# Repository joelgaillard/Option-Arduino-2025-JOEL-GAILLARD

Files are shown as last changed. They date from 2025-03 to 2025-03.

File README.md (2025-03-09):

# Matrix quiz - Documentation du Projet

Réalisé par `Joël Gaillard`
Option Arduino 2025 – COMEM+

[Code source](./main/main.ino) (./main/main.ino)
[Fichier Fritzing du schema](./docs/schematics.fzz) (./docs/schematics.fzz)
[Vidéo de démonstration du projet](./docs/assets/matrix-quiz-video-demo.mp4) (./docs/assets/matrix-quiz-video-demo.mp4)

## 1. Description et motivations du projet

### 1.1 Description

Ce projet consiste en un jeu interactif utilisant une matrice LED 8x8, trois écrans LCD 16x2, des leds et des boutons-poussoirs pour créer une expérience ludique et éducative. Le joueur doit identifier des images simples affichées sur la matrice LED et choisir la bonne réponse parmi trois propositions affichées sur trois écrans LCD distincts.

Le jeu comporte **trois modes** :

1. **Mode "Normal"** : 3 vies, score basé sur le temps et les erreurs.
2. **Mode "Time Limit"** : 4 secondes max par question.
3. **Mode "Mort subite"** : Une seule erreur met fin à la partie.

### 1.2 Motivations

- Expérimentation de divers composants arduino (dont la matrice que je trouve particulièrement intéressante)
- Proposer un mini-jeu ludique et interactif avec différents modes de jeux
- Proposer un passe temps lors de courts moments d'ennui à la HEIG-VD (lorsque l'on attend à la pause que la machine ait fini de faire le café par exemple :) )

## 2. État de l'art

### Projets similaires et inspirants

- Projet de quiz utilisant des leds, un lcd 16x2 et un buzzer: https://www.youtube.com/watch?v=HU-3VD1_Pgg
- Projet de dessins simples sur une matrice led arduino: https://youtube.com/shorts/jsiKtfHeaLs?si=bqF50zugfB3S6R69

## 3. Prototype final

Matrix Quiz

Matrix Quiz

Matrix Quiz

## 4. Circuit électronique

### Schéma

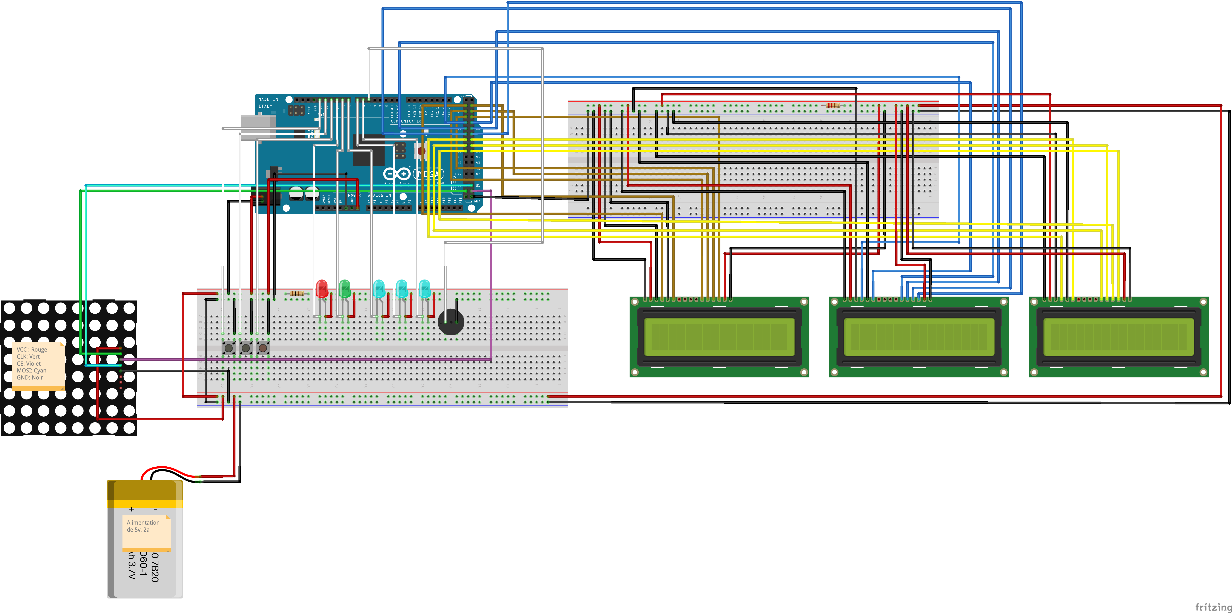
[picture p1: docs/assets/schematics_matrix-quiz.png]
Schéma du circuit


### BOM

| Réf  | Composant | Quantité | Description | Fournisseur / Lien |
| :--- | :--- | --- | :--- | :--- |
| 1 | Arduino Mega 2560 | 1 | Microcontrôleur ATmega2560, 54 I/O, 16 ADC | [Arduino](https://store.arduino.cc/products/arduino-mega-2560-rev3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) |
| 2 | Breadboard | 1 | Plaque de prototypage sans soudure | [Galaxus](https://www.galaxus.ch/de/s1/product/oem-steckplatine-breadboard-transparent-fullsize-breadboard-elektronikzubehoer-gehaeuse-5999390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) |
| 3 | Cable USB A-B | 1 | Alimentation et programmation Arduino | [Galaxus](https://www.galaxus.ch/fr/s1/product/value-usb-a-usb-b-3-m-usb-20-cable-usb-219216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) |
| 4 | 52Pi 8x8 RGB-Matrix mit 4 x 74HC595 - für Raspberry Pi und Arduino | 1 | Affichage matriciel couleur, 64 LEDs | [Play-Zone](https://www.play-zone.ch/en/52pi-8x8-rgb-matrix-mit-4-x-74hc595-fur-raspberry-pi-und-arduino.html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) |
| 5 | Joy-it com-lcd 16x2 Module écran 6.6 cm (2.6 pouces) 16 x 4 Pixel | 3 | Affichage alphanumérique 16 caractères x 2 lignes | [Conrad](https://www.conrad.ch/fr/p/joy-it-com-lcd-16x2-module-ecran-6-6-cm-2-6-pouces-16-x-4-pixel-convient-pour-kits-de-developpement-arduino-avec-re-1656369.html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) |
| 6 | Boutons poussoirs Sparkfun COM-10302 | 3 | Interrupteurs momentanés pour interaction | [Mouser](https://www.mouser.ch/ProductDetail/SparkFun/COM-10302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) |
| 7 | Leds bleues | 3 | Indicateur visuel | [Arduino](https://store.arduino.cc/products/set-of-70-assorted-color-5mm-leds?queryID=1b061a37cc74efad95f1c7123696f21e) |
| 8 | Led rouge | 1 | Indicateur d'erreur | [Arduino](https://store.arduino.cc/products/set-of-70-assorted-color-5mm-leds?queryID=1b061a37cc74efad95f1c7123696f21e) |
| 9 | Led verte | 1 | Indicateur de succès | [Arduino](https://store.arduino.cc/products/set-of-70-assorted-color-5mm-leds?queryID=1b061a37cc74efad95f1c7123696f21e) |
| 10 | Buzzer miniature Bruit généré: 85 dB Tension: 5 V/DC | 1 | Émission de sons | [Conrad](https://www.conrad.ch/fr/p/conrad-components-93038c212a-buzzer-miniature-bruit-genere-85-db-tension-5-v-dc-1-pc-s-1511467.html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) |
| 11 | Résistance 220 ohms | 1 | Limitation de courant | [Fruugo](https://www.fruugoschweiz.com/2600pcs-130-valeurs-resistances-assortiment-kit-1-ohm-ohm-025w-14w-kit-de-resistance-a-film-metallique-pour-elect/p-324038540-718095469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) |
| 12 | Résistance 100 ohms | 1 | Limitation de courant | [Fruugo](https://www.fruugoschweiz.com/2600pcs-130-valeurs-resistances-assortiment-kit-1-ohm-ohm-025w-14w-kit-de-resistance-a-film-metallique-pour-elect/p-324038540-718095469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) |
| 13 | Cables Dupont (41xM-F) (24xM-M) | 65 | Connexions entre composants | [Fruugo](https://www.fruugoschweiz.com/cable-de-fil-de-demarrage-40pin-dupont-breadboard-cables-male-a-femelle-male-a-male-femelle-a-femelle-pour-arduino-raspberry-pi-360pcs-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) |
| 14 | Alimentation externe de 5 volts et d'une puissance de 2 ampères | 1 | | |

## 5. Instructions de montage

**1. Alimentation générale**

- Alimentation externe +5 V → rail rouge de la breadboard principale
- Alimentation externe GND → rail bleu de la breadboard principale
- Broche Vin de l'Arduino → rail rouge de la breadboard principale

- Broche GND de l'Arduino → rail bleu de la breadboard principale
- Brancher l'arduino aux rails rouges et bleus de la breadboard principale (5V, GND)
- Relier les rails rouges et bleus des deux breadboards

**2. Connexion de la matrice LED 8×8**

- VCC → +5V,  rail rouge de la breadboard principale
- GND → GND, rail bleu de la breadboard principale
- CLK → Arduino D52
- MOSI → Arduino D51
- CE → Arduino D53

**3. Connexion des boutons poussoirs (3x)**

- Une patte → broches numériques de l'Arduino (D11, D12, D13)
- Autre patte → GND
- Pull-up activée dans le code (INPUT_PULLUP), donc pas besoin de résistance externe

**4. Connexion des LEDs indicatrices (5x, inversées)**

- Anodes reliées au +5V avec une résistance commune de 100Ω
- Cathodes reliées aux broches numériques de l'Arduino (D6, D7, D8, D9, D10)
- LED allumée lorsque la broche est mise à LOW

**5. Connexion du buzzer**

- Une borne → broche numérique de l'Arduino (D5)
- Autre borne → GND

**6. Connexion des trois écrans LCD 16×2**

| Fonction | LCD 1 | LCD 2 | LCD 3 |
|---|---|---|---|
| **Pin 1 (VSS)**  | Rail bleu (GND) | Rail bleu (GND) | Rail bleu (GND) |
| **Pin 2 (VDD)**  | Rail rouge (+5V) | Rail rouge (+5V) | Rail rouge (+5V) |
| **Pin 3 (VO - Contraste)** | Rail bleu (GND) | Rail bleu (GND) | Rail bleu (GND) |
| **Pin 4 (RS)** | D22 | D28 | D34 |
| **Pin 5 (R/W)** | Rail bleu (GND) | Rail bleu (GND) | Rail bleu (GND) |
| **Pin 6 (E - Enable)** | D23 | D29 | D35 |
| **Pin 7 (DB0)** | NON CONNECTÉ | NON CONNECTÉ | NON CONNECTÉ |
| **Pin 8 (DB1)** | NON CONNECTÉ | NON CONNECTÉ | NON CONNECTÉ |
| **Pin 9 (DB2)** | NON CONNECTÉ | NON CONNECTÉ | NON CONNECTÉ |
| **Pin 10 (DB3)** | NON CONNECTÉ | NON CONNECTÉ | NON CONNECTÉ |
| **Pin 11 (DB4)** | D24 | D30 | D36 |
| **Pin 12 (DB5)** | D25 | D31 | D37 |
| **Pin 13 (DB6)** | D26 | D32 | D38 |
| **Pin 14 (DB7)** | D27 | D33 | D39 |
| **Pin 15 (LED+)** | Rail rouge (+5V), avec une résistance de 220 ohms | Rail rouge (+5V), avec une résistance de 220 ohms | Rail rouge (+5V), avec une résistance de 220 ohms |
| **Pin 16 (LED–)** | Rail bleu (GND) | Rail bleu (GND) | Rail bleu (GND) |

**7. Mise sous tension et utilisation**

Programmation :

- Branchez l’Arduino à l’ordinateur via USB (le temps de téléverser le code)
- Téléversez le code présent dans ./main/main.ino

Alimentation finale :

- Débranchez l’USB
- Branchez votre alimentation externe
- L’Arduino fonctionne désormais en mode autonome, alimenté par l’externe.

## 6. Difficultés rencontrées et améliorations possibles

### Difficultés rencontrées

- Synchronisation et gestion simultanée des trois écrans LCD.
- Gestion de l'alimentation (dûs à l'affichage des écrans et de la matrice)
- Câblage complexe
- Problèmes de couleur avec la matrice

### Améliorations possibles

- Intégration d'un affichage OLED pour une meilleure expérience visuelle
- Ajout de modes de jeux supplémentaires
- Développement d'un mode multijoueur

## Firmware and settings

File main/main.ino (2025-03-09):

#include <SPI.h>         // Pour communiquer via le bus SPI avec la matrice
#include <Arduino.h>
#include <LiquidCrystal.h> // Pour gérer l'affichage sur LCD

// --- Instances d'écrans LCD (pins RS, E, D4, D5, D6, D7) ---
LiquidCrystal lcd1(22, 23, 24, 25, 26, 27);
LiquidCrystal lcd2(28, 29, 30, 31, 32, 33);
LiquidCrystal lcd3(34, 35, 36, 37, 38, 39);

// --- Brochage et constantes ---
#define PIN_CE         53      // Sortie "Chip Enable" pour la matrice via SPI
#define BUZZER_PIN     5       // Buzzer pour feedback sonore
#define RED_LED_PIN    10      // LED rouge (erreur)
#define GREEN_LED_PIN  9       // LED verte (bonne réponse)
const int BLUE_LED_PINS[] = {8, 7, 6}; // LEDs bleues (indicateur de vies)
const int BUTTON_PINS[]   = {13,12,11}; // 3 boutons pour la sélection de réponse

// Fréquences pour signal sonore
#define WIN_FREQUENCY  1000
#define LOSE_FREQUENCY 400

// Couleurs pour la matrice (3 bits : R/G/B)
#define NO_COLOR 0b000
#define RED      0b100
#define GREEN    0b010
#define BLUE     0b001
#define CYAN     0b011

// Modes de jeu
#define MODE_NORMAL       0
#define MODE_TIME_LIMIT   1
#define MODE_SUDDEN_DEATH 2
#define TIME_LIMIT_MS     4000  // 4 secondes max pour le mode Time Limit

// --- Tableaux d'images affichables sur la matrice (codés en R/G/B) ---
const uint8_t images[][8][8] = {
    // Chaque image est un tableau 8x8, chaque case indique la couleur

    // Grenouille
  {
    { NO_COLOR, GREEN, GREEN, GREEN, NO_COLOR, GREEN, GREEN, GREEN },
    { NO_COLOR, GREEN, CYAN, GREEN, NO_COLOR, GREEN, CYAN, GREEN },
    { GREEN, GREEN, GREEN, GREEN, GREEN, GREEN, GREEN, GREEN },
    { GREEN, RED, RED, RED, RED, RED, RED, RED },
    { GREEN, GREEN, GREEN, GREEN, GREEN, GREEN, GREEN, GREEN },
    { GREEN, GREEN, GREEN, GREEN, GREEN, GREEN, GREEN, GREEN },
    { GREEN, GREEN, GREEN, GREEN, GREEN, GREEN, GREEN, GREEN },
    { GREEN, GREEN, NO_COLOR, GREEN, GREEN, GREEN, NO_COLOR, GREEN }
  },
      // Oiseau
  {
    { NO_COLOR, NO_COLOR, CYAN, CYAN, NO_COLOR, NO_COLOR, NO_COLOR, NO_COLOR },
    { NO_COLOR, CYAN, CYAN, CYAN, CYAN, NO_COLOR, NO_COLOR, NO_COLOR },
    { RED, CYAN, BLUE, CYAN, CYAN, NO_COLOR, NO_COLOR, GREEN },
    { NO_COLOR, CYAN, CYAN, CYAN, GREEN, GREEN, GREEN, GREEN },
    { NO_COLOR, CYAN, CYAN, CYAN, GREEN, GREEN, GREEN, GREEN },
    { NO_COLOR, NO_COLOR, CYAN, CYAN, CYAN, CYAN, CYAN, NO_COLOR },
    { NO_COLOR, NO_COLOR, CYAN, CYAN, CYAN, CYAN, CYAN, NO_COLOR },
    { NO_COLOR, NO_COLOR, RED, NO_COLOR, RED, NO_COLOR, NO_COLOR, NO_COLOR }
  },
      // Arbre
  {
    { NO_COLOR, NO_COLOR, GREEN, GREEN, GREEN, GREEN, NO_COLOR, NO_COLOR },
    { NO_COLOR, GREEN, GREEN, GREEN, GREEN, GREEN, GREEN, NO_COLOR },
    { NO_COLOR, GREEN, GREEN, GREEN, GREEN, GREEN, GREEN, NO_COLOR },
    { NO_COLOR, GREEN, GREEN, GREEN, GREEN, GREEN, GREEN, NO_COLOR },
    { NO_COLOR, NO_COLOR, GREEN, GREEN, GREEN, GREEN, NO_COLOR, NO_COLOR },
    { NO_COLOR, NO_COLOR, NO_COLOR, RED, RED, NO_COLOR, NO_COLOR, NO_COLOR },
    { NO_COLOR, NO_COLOR, NO_COLOR, RED, RED, NO_COLOR, NO_COLOR, NO_COLOR },
    { NO_COLOR, NO_COLOR, NO_COLOR, RED, RED, NO_COLOR, NO_COLOR, NO_COLOR }
  },
      // Coeur
  {
    { NO_COLOR, RED, RED, NO_COLOR, NO_COLOR, RED, RED, NO_COLOR },
    { RED, RED, RED, RED, RED, RED, RED, RED },
    { RED, RED, RED, RED, RED, RED, RED, RED },
    { RED, RED, RED, RED, RED, RED, RED, RED },
    { RED, RED, RED, RED, RED, RED, RED, RED },
    { NO_COLOR, RED, RED, RED, RED, RED, RED, NO_COLOR },
    { NO_COLOR, NO_COLOR, RED, RED, RED, RED, NO_COLOR, NO_COLOR },
    { NO_COLOR, NO_COLOR, NO_COLOR, RED, RED, NO_COLOR, NO_COLOR, NO_COLOR }
  },
  // Serpent
  {
    { NO_COLOR,NO_COLOR,NO_COLOR,NO_COLOR,NO_COLOR,NO_COLOR,NO_COLOR,GREEN },
    { NO_COLOR,GREEN,  GREEN,  GREEN,  GREEN,  GREEN,  GREEN,  GREEN },
    { NO_COLOR,GREEN,  NO_COLOR,NO_COLOR,NO_COLOR,NO_COLOR,NO_COLOR,NO_COLOR },
    { NO_COLOR,GREEN,  GREEN,  GREEN,  GREEN,  GREEN,  NO_COLOR,NO_COLOR },
    { NO_COLOR,NO_COLOR,NO_COLOR,NO_COLOR,NO_COLOR,GREEN,  NO_COLOR,NO_COLOR },
    { CYAN,  GREEN, CYAN,  GREEN,  GREEN,  GREEN,  NO_COLOR,NO_COLOR },
    { GREEN,  GREEN,  GREEN,  NO_COLOR,NO_COLOR,NO_COLOR,NO_COLOR,NO_COLOR },
    { RED,    NO_COLOR,NO_COLOR,NO_COLOR,NO_COLOR,NO_COLOR,NO_COLOR,NO_COLOR }
  },
  // Tête de mort
  {
    { RED,RED,RED,RED,RED,RED,RED,RED },
    { RED,RED,RED,RED,RED,RED,RED,RED },
    { RED,RED,RED,RED,RED,RED,RED,RED },
    { RED,NO_COLOR,RED,RED,RED,NO_COLOR,RED,RED },
    { RED,RED,RED,NO_COLOR,RED,RED,RED,RED },
    { RED,RED,RED,RED,RED,RED,RED,RED },
    { NO_COLOR,RED,NO_COLOR,RED,NO_COLOR,RED,NO_COLOR,NO_COLOR },
    { NO_COLOR,RED,NO_COLOR,RED,NO_COLOR,RED,NO_COLOR,NO_COLOR }
  },
  // Dinosaure
  {
    { NO_COLOR,GREEN, GREEN, GREEN, GREEN, GREEN, NO_COLOR,NO_COLOR },
    { GREEN,   NO_COLOR,GREEN, NO_COLOR,GREEN, NO_COLOR,NO_COLOR,NO_COLOR },
    { GREEN,   GREEN,  GREEN, GREEN, GREEN, NO_COLOR,NO_COLOR,NO_COLOR },
    { NO_COLOR,NO_COLOR,GREEN, GREEN, GREEN, NO_COLOR,NO_COLOR,NO_COLOR },
    { NO_COLOR,GREEN,  CYAN,  GREEN,GREEN, NO_COLOR,GREEN, NO_COLOR },
    { NO_COLOR,NO_COLOR,CYAN, CYAN,GREEN, NO_COLOR,GREEN, NO_COLOR },
    { NO_COLOR,NO_COLOR,CYAN, CYAN,GREEN, GREEN, NO_COLOR,NO_COLOR },
    { NO_COLOR,NO_COLOR,GREEN, NO_COLOR,GREEN,NO_COLOR,NO_COLOR,NO_COLOR }
  },
  // Cadenas
  {
    { NO_COLOR,NO_COLOR,BLUE,  BLUE, BLUE, NO_COLOR,NO_COLOR,NO_COLOR },
    { NO_COLOR,BLUE,    NO_COLOR,NO_COLOR,NO_COLOR,BLUE, NO_COLOR,NO_COLOR },
    { NO_COLOR,BLUE,    NO_COLOR,NO_COLOR,NO_COLOR,BLUE, NO_COLOR,NO_COLOR },
    { BLUE,    BLUE,    BLUE,   BLUE, BLUE, BLUE,  BLUE,   NO_COLOR },
    { BLUE,    BLUE,    BLUE,   NO_COLOR,BLUE,BLUE,BLUE,   NO_COLOR },
    { BLUE,    BLUE,    BLUE,   NO_COLOR,BLUE,BLUE,BLUE,   NO_COLOR },
    { BLUE,    BLUE,    BLUE,   BLUE, BLUE, BLUE,  BLUE,   NO_COLOR },
    { NO_COLOR,NO_COLOR,BLUE,   BLUE, BLUE, NO_COLOR,NO_COLOR,NO_COLOR }
  }
};

// On associe chaque image à une réponse textuelle
static const int NB_IMAGES = sizeof(images) / sizeof(images[0]);
const char* answers[] = {
  "Grenouille","Oiseau","Arbre","Coeur","Serpent",
  "Tete de mort","Dinosaure","Cadenas"
};

// Variables de jeu
int imageOrder[NB_IMAGES], questionIndex, currentImage=-1, correctButton;
String options[3];
int lives=3, gameMode=0;
bool timeLimitActive=false;
unsigned long lastPressTime=0, gameStartTime=0;
long bestScore=0;

// --- Fonctions déclarées plus bas ---
void selectGameMode();
void resetGame();
void shuffleImages();
void nextQuestion();
void generateQuestion();
void displayMatrix();
void displayRow(uint8_t row);
void checkButtonPress();
long computeScore(unsigned long totalTimeMs,int finalLives);
void showFullColor(uint8_t color, unsigned long ms);
void playVictoryTune();
void playGameOverTune();

// --- Initialisation des pins et setup des LCD ---
void setup(){
  pinMode(PIN_CE, OUTPUT);
  SPI.begin(); // Initialisation du bus SPI pour la matrice

  // Boutons en INPUT_PULLUP : ils seront à l'état LOW quand pressés
  for(int i=0;i<3;i++)
    pinMode(BUTTON_PINS[i], INPUT_PULLUP);

  // LEDs en sortie (rouge, verte, bleues = vies)
  pinMode(RED_LED_PIN, OUTPUT);
  pinMode(GREEN_LED_PIN, OUTPUT);
  for(int i=0;i<3;i++) 
    pinMode(BLUE_LED_PINS[i], OUTPUT);

  // Extinction par défaut (LEDs en HIGH car câblage inversé)
  digitalWrite(RED_LED_PIN, HIGH);
  digitalWrite(GREEN_LED_PIN, HIGH);
  for(int i=0;i<3;i++)
    digitalWrite(BLUE_LED_PINS[i], HIGH);

  // Initialisation des LCD 16×2
  lcd1.begin(16,2);
  lcd2.begin(16,2);
  lcd3.begin(16,2);

  // On demande à l'utilisateur de choisir le mode de jeu
  selectGameMode();
}

void loop(){
  // Affichage en continu de la matrice (pour éviter flicker)
  displayMatrix();
  // Contrôle si un bouton est pressé
  checkButtonPress();
}

// --- Choix du mode de jeu via les boutons ---
void selectGameMode(){
  // Affiche un titre sur chaque LCD
  lcd1.clear(); lcd1.print("Mode Normal");    lcd1.setCursor(0,1); lcd1.print("(Btn1)");
  lcd2.clear(); lcd2.print("Time Limit");     lcd2.setCursor(0,1); lcd2.print("(Btn2)");
  lcd3.clear(); lcd3.print("Mort subite");    lcd3.setCursor(0,1); lcd3.print("(Btn3)");

  // Boucle jusqu'au choix
  while(true){
    for(int i=0;i<3;i++){
      if(!digitalRead(BUTTON_PINS[i])){ // Pression bouton
        delay(200); // Anti-rebond simple
        if(i==0){ 
          gameMode=MODE_NORMAL;      
          lcd1.clear(); lcd1.print("Normal OK!");
        }
        if(i==1){ 
          gameMode=MODE_TIME_LIMIT;  
          lcd2.clear(); lcd2.print("TimeLim OK!");
        }
        if(i==2){ 
          gameMode=MODE_SUDDEN_DEATH;
          lcd3.clear(); lcd3.print("MortSub OK!");
        }
        delay(500);
        resetGame(); 
        return;
      }
    }
  }
}

// --- Réinitialise les paramètres pour une nouvelle partie ---
void resetGame(){
  questionIndex = 0;
  currentImage  = -1;
  correctButton = 0;
  lastPressTime = 0;
  timeLimitActive = false;

  // Vies selon le mode
  if(gameMode == MODE_SUDDEN_DEATH) 
    lives = 1;
  else 
    lives = 3;

  // Affiche les vies (LEDs bleues) ; si i < lives → LED ON (LOW)
  for(int i=0;i<3;i++)
    digitalWrite(BLUE_LED_PINS[i], (i<lives) ? LOW : HIGH);

  // En mode normal, on démarre un chrono pour le score final
  if(gameMode == MODE_NORMAL)
    gameStartTime = millis();

  // Mélange l'ordre des images et démarre la première question
  shuffleImages();
  nextQuestion();
}

// --- Mélange le tableau d'images de façon aléatoire ---
void shuffleImages(){
  for(int i=0; i<NB_IMAGES; i++)
    imageOrder[i] = i;
  for(int i=0; i<NB_IMAGES; i++){
    int j = random(NB_IMAGES);
    int tmp = imageOrder[i];
    imageOrder[i] = imageOrder[j];
    imageOrder[j] = tmp;
  }
}

// --- Passe à la question suivante ---
void nextQuestion(){
  if(questionIndex >= NB_IMAGES){
    // Plus d'images = victoire
    lcd1.clear(); lcd1.print("BRAVO!");
    lcd2.clear(); lcd2.print("BRAVO!");
    lcd3.clear(); lcd3.print("BRAVO!");
    showFullColor(GREEN, 1000); // Écran vert
    playVictoryTune();

    // Si mode normal, calcul du score final
    if(gameMode == MODE_NORMAL){
      unsigned long totalTime = millis() - gameStartTime;
      long s = computeScore(totalTime, lives);
      lcd1.setCursor(0,1); lcd1.print("Score:"); lcd1.print(s);
      // On vérifie si c'est un record
      if(s > bestScore){
        bestScore = s;
        lcd2.setCursor(0,1); lcd2.print("Nouveau record!");
      }
    }
    delay(3000);
    selectGameMode(); // Retour au choix de mode
    return;
  }
  // Sélectionne la prochaine image
  currentImage = imageOrder[questionIndex++];
  generateQuestion();

  // En mode Time Limit ou Mort subite, on active le délai
  timeLimitActive = (gameMode == MODE_TIME_LIMIT || gameMode == MODE_SUDDEN_DEATH);
  lastPressTime   = millis();
}

// --- Prépare l'affichage des réponses possibles, dont une correcte ---
void generateQuestion(){
  correctButton = random(0,3);
  int idx = currentImage;
  options[correctButton] = answers[idx];

  int totalAnswers = NB_IMAGES;
  for(int i=0;i<3;i++){
    if(i != correctButton){
      int w;
      // On cherche une réponse incorrecte, pas déjà utilisée
      do { w = random(totalAnswers); }
      while(w == idx || options[0] == answers[w] || options[1] == answers[w]);
      options[i] = answers[w];
    }
  }

  // Affiche le texte de chaque option sur un LCD
  lcd1.clear(); lcd1.print(options[0].substring(0,16));
  lcd2.clear(); lcd2.print(options[1].substring(0,16));
  lcd3.clear(); lcd3.print(options[2].substring(0,16));
}

// --- Gère l'affichage de la matrice (rafraîchissement ligne par ligne) ---
void displayMatrix(){
  if(currentImage < 0) return; // Pas d'image si pas de question
  for(uint8_t r=0; r<8; r++){
    displayRow(r);
    delayMicroseconds(200); 
  }
}

// --- Affiche une ligne de la matrice (sélectionne R/G/B) ---
void displayRow(uint8_t row){
  uint8_t rm=0, gm=0, bm=0; // masques pour rouge, vert, bleu
  for(uint8_t c=0; c<8; c++){
    uint8_t col = images[currentImage][row][c];
    if(col & RED)   rm |= (1 << c);
    if(col & GREEN) gm |= (1 << c);
    if(col & BLUE)  bm |= (1 << c);
  }
  // Transmission en SPI : on envoie la "ligne" pour R, B, G
  digitalWrite(PIN_CE, LOW);
  SPI.transfer(~rm);
  SPI.transfer(~bm);
  SPI.transfer(~gm);
  SPI.transfer(1 << row);
  digitalWrite(PIN_CE, HIGH);
}

// --- Vérifie si un bouton de réponse est pressé, gère la logique de victoire / erreur ---
void checkButtonPress(){
  // Gère la limite de temps si mode Time Limit / Mort subite
  if(timeLimitActive && (millis() - lastPressTime > TIME_LIMIT_MS)){
    // Temps écoulé = erreur
    digitalWrite(RED_LED_PIN, LOW);
    showFullColor(RED, 500); // Écran rouge
    tone(BUZZER_PIN, LOSE_FREQUENCY); 
    delay(500);
    digitalWrite(RED_LED_PIN, HIGH);
    noTone(BUZZER_PIN);

    // En mort subite : fin de partie directe
    if(gameMode == MODE_SUDDEN_DEATH){
      lcd1.clear(); lcd1.print("GAME OVER");
      lcd2.clear(); lcd2.print("GAME OVER");
      lcd3.clear(); lcd3.print("GAME OVER");
      showFullColor(RED,1000);
      playGameOverTune();
      delay(2000);
      selectGameMode();
      return;
    } else {
      // Sinon, on perd une vie
      if(lives>0) digitalWrite(BLUE_LED_PINS[--lives], HIGH);
      if(lives<=0){
        // Plus de vies = game over
        lcd1.clear(); lcd1.print("GAME OVER");
        lcd2.clear(); lcd2.print("GAME OVER");
        lcd3.clear(); lcd3.print("GAME OVER");
        showFullColor(RED, 1000);
        playGameOverTune();
        delay(2000);
        selectGameMode();
        return;
      }
    }
    // On passe à la prochaine question
    nextQuestion();
    return;
  }

  // Si un bouton est pressé...
  for(int i=0;i<3;i++){
    if(!digitalRead(BUTTON_PINS[i])){ // LOW = press
      delay(200); // Anti-rebond
      if(i == correctButton){
        // Bonne réponse
        digitalWrite(GREEN_LED_PIN, LOW);
        showFullColor(GREEN, 500);
        tone(BUZZER_PIN, WIN_FREQUENCY);
        delay(500);
        digitalWrite(GREEN_LED_PIN, HIGH);
        noTone(BUZZER_PIN);

        // Si c'était la dernière question
        if(questionIndex >= NB_IMAGES){
          lcd1.clear(); lcd1.print("VICTOIRE!");
          showFullColor(GREEN, 800);
          playVictoryTune();
          if(gameMode == MODE_NORMAL){
            long s = computeScore(millis()-gameStartTime, lives);
            lcd2.clear(); lcd2.print("Score:"); lcd2.print(s);
            // Vérifie record
            if(s>bestScore){
              bestScore=s;
              lcd3.clear(); lcd3.print("Nouveau record");
            }
          }
          delay(2000);
          selectGameMode();
          return;
        } else {
          nextQuestion();
        }
      } else {
        // Mauvaise réponse
        digitalWrite(RED_LED_PIN, LOW);
        showFullColor(RED, 500);
        tone(BUZZER_PIN, LOSE_FREQUENCY);
        delay(500);
        digitalWrite(RED_LED_PIN, HIGH);
        noTone(BUZZER_PIN);

        if(gameMode == MODE_SUDDEN_DEATH){
          // En mort subite, erreur = fin du jeu
          lcd1.clear(); lcd1.print("GAME OVER");
          lcd2.clear(); lcd2.print("GAME OVER");
          lcd3.clear(); lcd3.print("GAME OVER");
          showFullColor(RED, 1000);
          playGameOverTune();
          delay(2000);
          selectGameMode();
          return;
        } else {
          // Sinon, on perd une vie
          if(lives > 0) digitalWrite(BLUE_LED_PINS[--lives], HIGH);
          if(lives <= 0){
            // Plus de vies = game over
            lcd1.clear(); lcd1.print("GAME OVER");
            lcd2.clear(); lcd2.print("GAME OVER");
            lcd3.clear(); lcd3.print("GAME OVER");
            showFullColor(RED, 1000);
            playGameOverTune();
            delay(2000);
            selectGameMode();
            return;
          }
          // Passe à la question suivante
          nextQuestion();
        }
      }
      return;
    }
  }
}

// --- Calcul simple de score : dépend du temps et du nombre de vies restantes ---
long computeScore(unsigned long t, int lf){
  // On peut modifier la formule pour ajuster la difficulté
  long s = (lf * 10000L) - (long)(t / 100);
  return (s < 0) ? 0 : s;
}

// --- Affiche une couleur plein écran sur la matrice pendant 'ms' millisecondes ---
void showFullColor(uint8_t color, unsigned long ms){
  unsigned long t = millis();
  while(millis() - t < ms){
    for(uint8_t row=0; row<8; row++){
      uint8_t rm=0, gm=0, bm=0;
      // Sur chaque ligne, on active tous les pixels de la couleur choisie
      for(uint8_t col=0; col<8; col++){
        if(color & RED)   rm |= (1 << col);
        if(color & GREEN) gm |= (1 << col);
        if(color & BLUE)  bm |= (1 << col);
      }
      digitalWrite(PIN_CE, LOW);
      SPI.transfer(~rm);
      SPI.transfer(~bm);
      SPI.transfer(~gm);
      SPI.transfer(1 << row);
      digitalWrite(PIN_CE, HIGH);
      delayMicroseconds(200);
    }
  }
}

// --- Jouer un "jingle" de victoire ---
void playVictoryTune(){
  int melody[] = { 262, 294, 330, 392 }; // Do, Ré, Mi, Sol
  for(int i=0; i<4; i++){
    tone(BUZZER_PIN, melody[i], 200);
    delay(250);
  }
  noTone(BUZZER_PIN);
}

// --- Jouer un "jingle" de game over ---
void playGameOverTune(){
  int melody[] = { 392, 330, 294, 262 }; // Sol, Mi, Ré, Do (descendant)
  for(int i=0; i<4; i++){
    tone(BUZZER_PIN, melody[i], 200);
    delay(250);
  }
  tone(BUZZER_PIN, 200, 400); // Note plus grave, plus longue
  delay(450);
  noTone(BUZZER_PIN);
}
